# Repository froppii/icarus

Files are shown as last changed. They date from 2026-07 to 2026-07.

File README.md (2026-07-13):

# icarus
a retro vhs player themed mp3 player, complete with tactile switches and a fun volume button

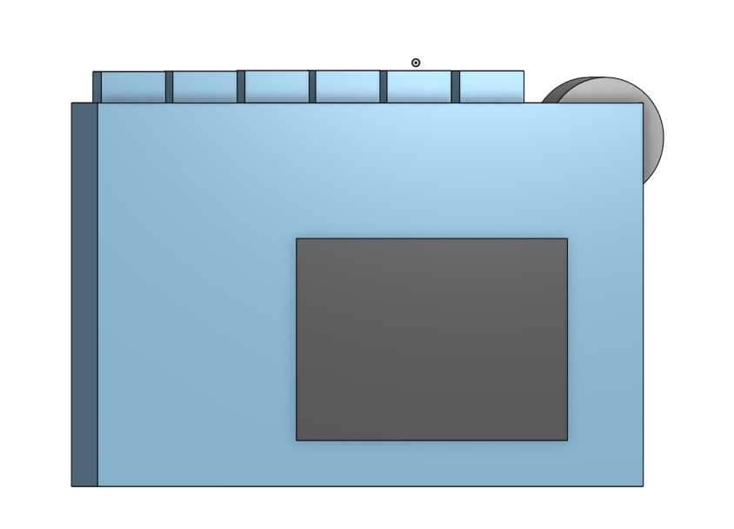
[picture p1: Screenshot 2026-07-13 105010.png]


## why?
ive always wanted a dedicated mp3 player so i can listen to music separately without draining my phone battery too quickly, aswell as not having to use spotify. im also learning more on how to make pcbs and 3d model case from this!

## parts and features
**parts**:
- mcu: esp32 s3 wroom 1
- dac: TAD5212IRGER
- display: ili9431
- power: 3.7V 2000mAh lipo battery
- pcb: 4 layers

**features**:
- 3.5mm headphone jack
- 2.8 inch display
- full sized sd card + 1-bit sdmmc audio streaming
- 5 tactile switches and a rotary encoder
- bluetooth 5.0
- programmable eq

## PCB
4 layer pcb

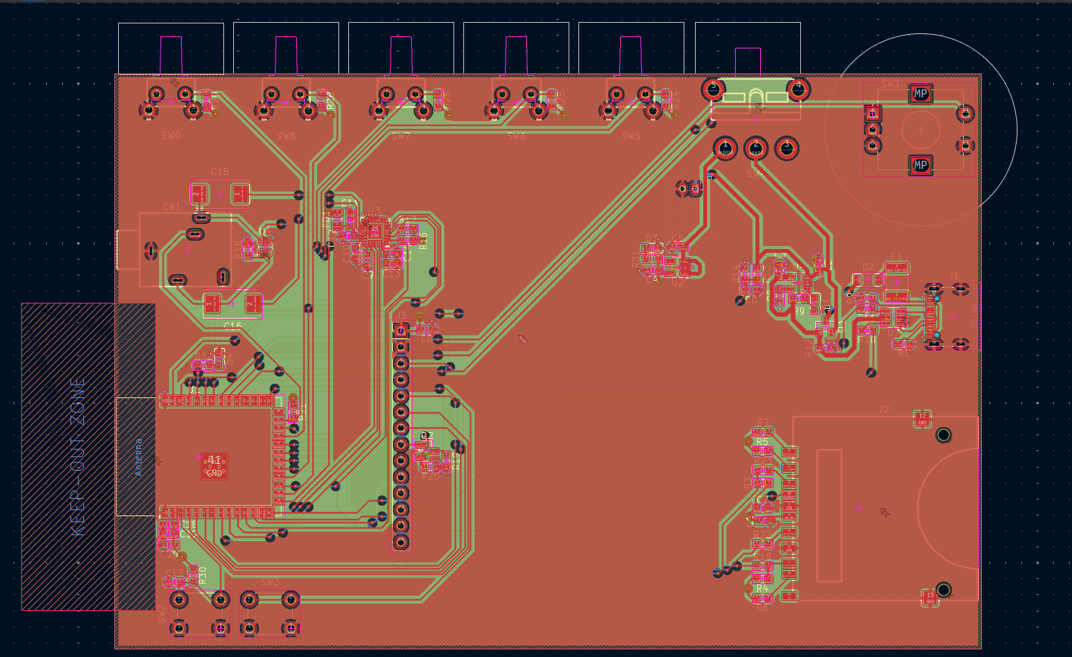
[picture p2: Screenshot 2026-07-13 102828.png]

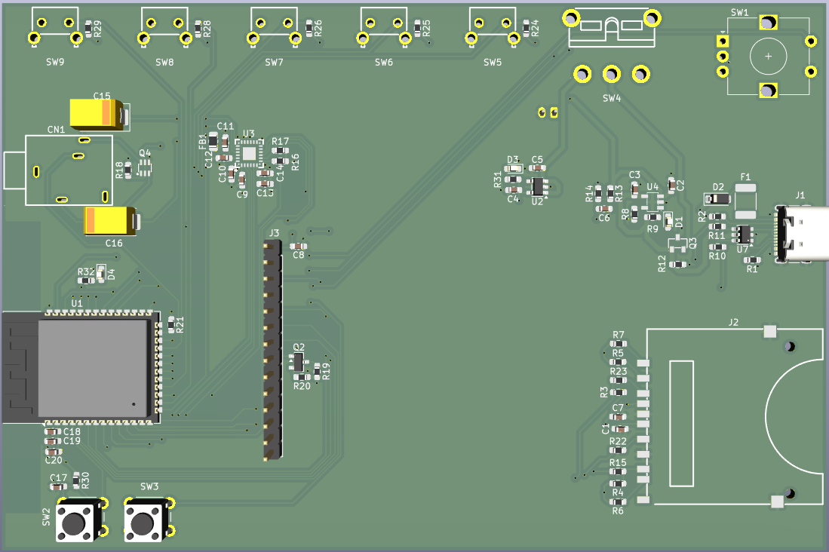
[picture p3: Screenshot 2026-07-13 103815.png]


## case
the case is still WIP! but i made a cad to show the general gist of how it would look like



## firmware
firmware coming soon

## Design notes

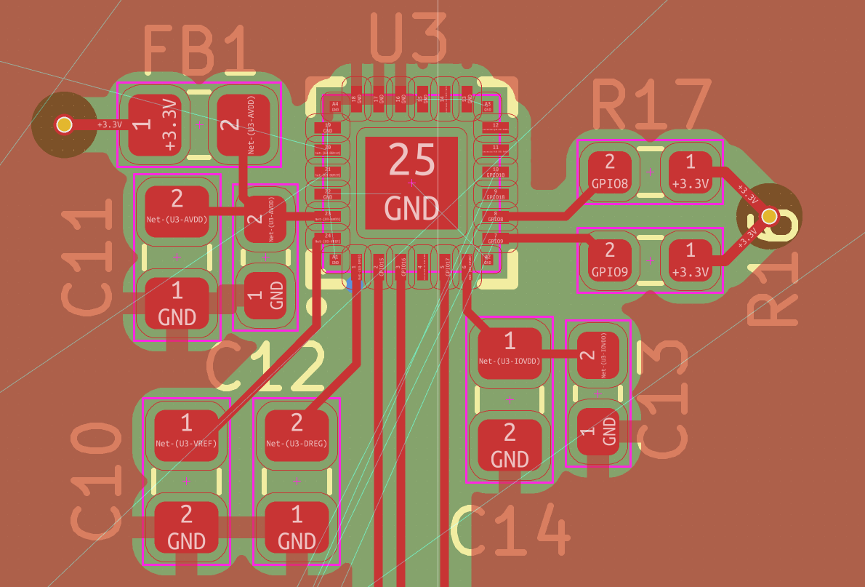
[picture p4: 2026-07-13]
Screenshot 2026-07-12 231309.png

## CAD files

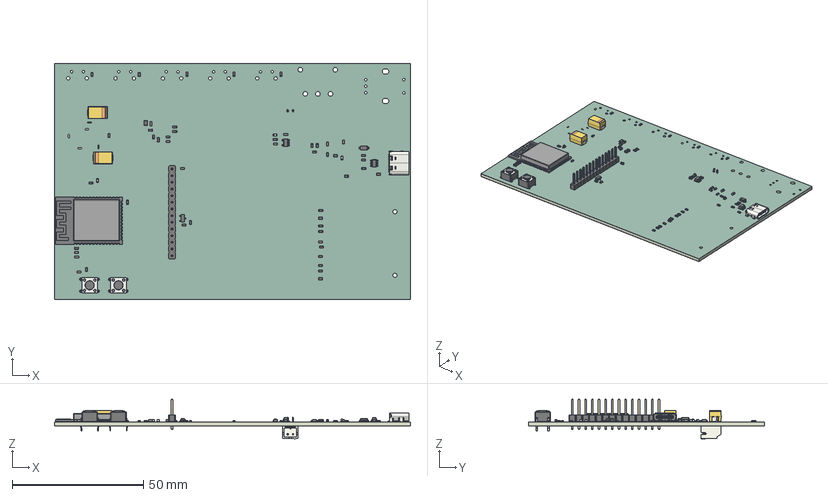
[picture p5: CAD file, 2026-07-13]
icarus.step
135.5 x 90.0 x 15.1 mm
R_0603_1608Metric x 31
C_0603_1608Metric x 18
R_0805_2012Metric
CP_EIA_7343_43_Kemet_X x 2
PinHeader_1x14_P254mm_Vertical
LED_0603_1608Metric x 3
SW_PUSH_6mm x 2
USB_C_Receptacle_16P_TopMnt_Horizontal_GCT_USB4105-xx-A
SOT-23
SOT-23-5
D_SOD-123
SOT-23-6
ESP32-S3-WROOM-1
JST_S2B_PH_K
icarus_soldermask x 2
icarus_PCB

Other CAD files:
.step

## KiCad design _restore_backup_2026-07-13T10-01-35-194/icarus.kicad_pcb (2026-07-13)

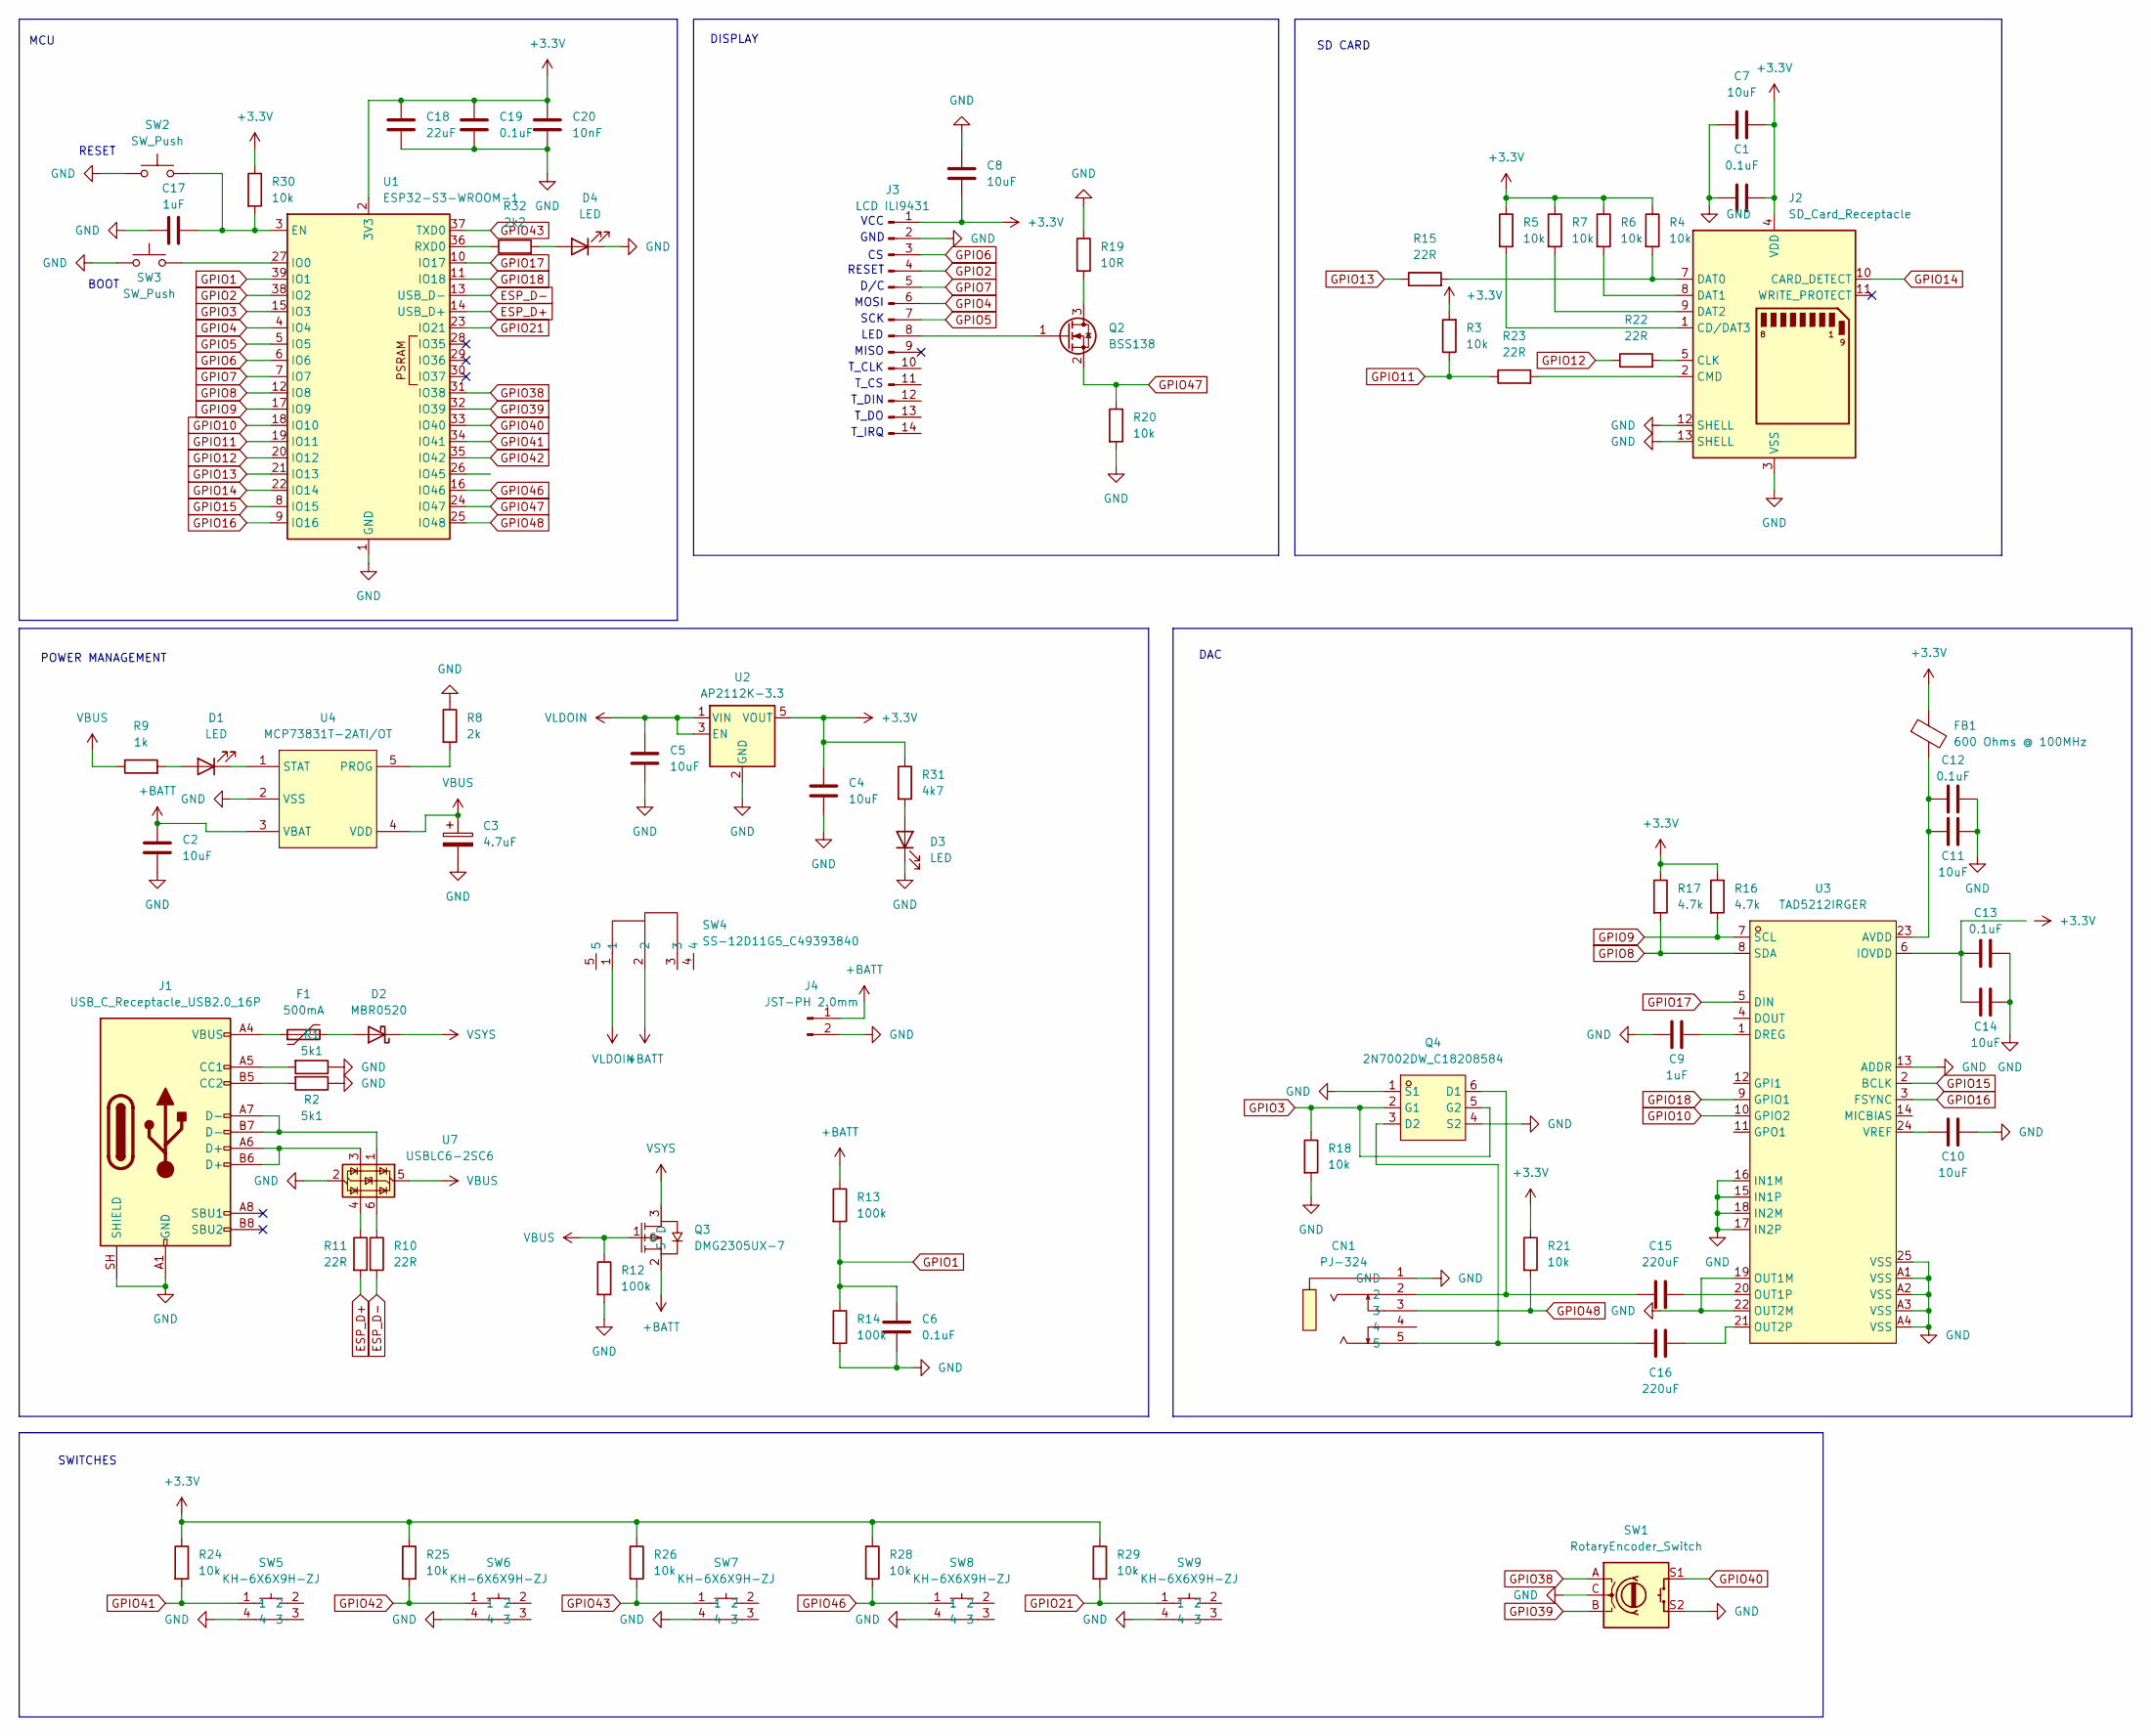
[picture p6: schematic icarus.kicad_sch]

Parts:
C1, C6, C12, C13, C19: 0.1uF; C_0603_1608Metric_Pad1.08x0.95mm_HandSolder
C2, C4, C5, C7, C8, C10, C11, C14: 10uF; C_0603_1608Metric_Pad1.08x0.95mm_HandSolder
C3: 4.7uF; C_0603_1608Metric_Pad1.08x0.95mm_HandSolder
C9, C17: 1uF; C_0603_1608Metric_Pad1.08x0.95mm_HandSolder
C15, C16: 220uF; CP_EIA-7343-43_Kemet-X_HandSolder
C18: 22uF; C_0603_1608Metric_Pad1.08x0.95mm_HandSolder
C20: 10nF; C_0603_1608Metric_Pad1.08x0.95mm_HandSolder
CN1: PJ-324; AUDIO-TH_PJ-324-M; MPN PJ-324; LCSC Part C22355738
D1, D3, D4: LED; LED_0603_1608Metric_Pad1.05x0.95mm_HandSolder
D2: MBR0520; D_SOD-123
F1: 500mA; Fuse_1812_4532Metric_Pad1.30x3.40mm_HandSolder
FB1: 600 Ohms @ 100MHz; R_0805_2012Metric_Pad1.20x1.40mm_HandSolder
J1: USB_C_Receptacle_USB2.0_16P; USB_C_Receptacle_GCT_USB4105-xx-A_16P_TopMnt_Horizontal
J2: SD_Card_Receptacle; SD-SMD_SD-006S-T
J3: LCD ILI9431; PinHeader_1x14_P2.54mm_Vertical
J4: JST-PH 2.0mm; JST_PH_S2B-PH-K_1x02_P2.00mm_Horizontal
Q2: BSS138; SOT-23
Q3: DMG2305UX-7; SOT-23-3_L2.9-W1.3-P1.90-LS2.4-BR; MPN DMG2305UX-7; LCSC Part C150470
Q4: 2N7002DW_C18208584; SOT-363_L2.1-W1.3-P0.65-LS2.3-BL; MPN 2N7002DW; LCSC Part C18208584
R1, R2: 5k1; R_0603_1608Metric_Pad0.98x0.95mm_HandSolder
R3, R4, R5, R6, R7, R18, R20, R21, R24, R25, R26, R28, R29, R30: 10k; R_0603_1608Metric_Pad0.98x0.95mm_HandSolder
R8: 2k; R_0603_1608Metric_Pad0.98x0.95mm_HandSolder
R9: 1k; R_0603_1608Metric_Pad0.98x0.95mm_HandSolder
R10, R11, R15, R22, R23: 22R; R_0603_1608Metric_Pad0.98x0.95mm_HandSolder
R12, R13, R14: 100k; R_0603_1608Metric_Pad0.98x0.95mm_HandSolder
R16, R17: 4.7k; R_0603_1608Metric_Pad0.98x0.95mm_HandSolder
R19: 10R; R_0603_1608Metric_Pad0.98x0.95mm_HandSolder
R31: 4k7; R_0603_1608Metric_Pad0.98x0.95mm_HandSolder
R32: 2k2; R_0603_1608Metric_Pad0.98x0.95mm_HandSolder
SW1: RotaryEncoder_Switch; RotaryEncoder_Alps_EC12E-Switch_Vertical_H20mm
SW2, SW3: SW_Push; SW_PUSH_6mm
SW4: SS-12D11G5_C49393840; SW-TH_SS-12D11G5; MPN SS-12D11G5; LCSC Part C49393840
SW5, SW6, SW7, SW8, SW9: KH-6X6X9H-ZJ; SW-TH_KH-6X6X9H-ZJ; MPN KH-6X6X9H-ZJ; LCSC Part C2837545
U1: ESP32-S3-WROOM-1
U2: AP2112K-3.3; SOT-23-5
U3: TAD5212IRGER; VQFN-24_L4.0-W4.0-P0.50-BL-EP2.1_1; MPN TAD5212IRGER; LCSC Part C45068920
U4: MCP73831T-2ATI/OT; SOT-23-5_L3.0-W1.7-P0.95-LS2.8-BR; MPN MCP73831T-2ATI/OT; LCSC Part C14879
U7: USBLC6-2SC6; SOT-23-6

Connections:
+3.3V: C1.2, C4.1, C7.1, C8.2, C18.1, C19.1, C20.1, FB1.1, J2.4 (VDD), J3.1, R3.2, R4.1, R5.1, R6.1, R7.1, R16.1, R17.1, R21.1, R24.1, R25.1, R26.1, R28.1, R29.1, R30.1, R31.1, U1.2 (3V3), U2.5 (VOUT)
+BATT: C2.1, J4.1, Q3.2 (S), R13.1, SW4.2, U4.3 (VBAT)
ESP_D+: R11.2, U1.14 (USB_D+)
ESP_D-: R10.2, U1.13 (USB_D-)
GND: C1.1, C2.2, C3.2, C4.2, C5.2, C6.2, C7.2, C8.1, C9.1, C10.2, C11.1, C12.1, C13.1, C14.2, C17.1, C18.2, C19.2, C20.2, CN1.1 (GND), D3.1 (K), D4.1 (K), J1.A1 (GND), J1.A12 (GND), J1.B1 (GND), J1.B12 (GND), J1.SH (SHIELD), J2.3 (VSS), J2.6 (VSS), J2.12 (SHELL), J2.13 (SHELL), J3.2, J4.2, Q4.1 (S1), Q4.4 (S2), R1.1, R2.1, R8.1, R12.2, R14.2, R18.2, R19.1, R20.2, SW1.C, SW1.S2, SW2.1, SW3.1, SW5.4, SW6.4, SW7.4, SW8.4, SW9.4, U1.1 (GND), U1.40 (GND), U1.41 (GND), U2.2 (GND), U3.13 (ADDR), U3.15 (IN1P), U3.16 (IN1M), U3.17 (IN2P), U3.18 (IN2M), U3.19 (OUT1M), U3.22 (OUT2M), U3.25 (VSS), U3.A1 (VSS), U3.A2 (VSS), U3.A3 (VSS), U3.A4 (VSS), U4.2 (VSS), U7.2 (GND)
GPIO1: C6.1, R13.2, R14.1, U1.39 (IO1)
GPIO2: J3.4, U1.38 (IO2)
GPIO3: Q4.2 (G1), Q4.5 (G2), R18.1, U1.15 (IO3)
GPIO4: J3.6, U1.4 (IO4)
GPIO5: J3.7, U1.5 (IO5)
GPIO6: J3.3, U1.6 (IO6)
GPIO7: J3.5, U1.7 (IO7)
GPIO8: R17.2, U1.12 (IO8), U3.8 (SDA)
GPIO9: R16.2, U1.17 (IO9), U3.7 (SCL)
GPIO10: U1.18 (IO10), U3.10 (GPIO2)
GPIO11: R3.1, R23.1, U1.19 (IO11)
GPIO12: R22.1, U1.20 (IO12)
GPIO13: R15.1, U1.21 (IO13)
GPIO14: J2.10 (CARD_DETECT), U1.22 (IO14)
GPIO15: U1.8 (IO15), U3.2 (BCLK)
GPIO16: U1.9 (IO16), U3.3 (FSYNC)
GPIO17: U1.10 (IO17), U3.5 (DIN)
GPIO18: U1.11 (IO18), U3.9 (GPIO1)
GPIO21: R29.2, SW9.1, U1.23 (IO21)
GPIO38: SW1.A, U1.31 (IO38)
GPIO39: SW1.B, U1.32 (IO39)
GPIO40: SW1.S1, U1.33 (IO40)
GPIO41: R24.2, SW5.1, U1.34 (IO41)
GPIO42: R25.2, SW6.1, U1.35 (IO42)
GPIO43: R26.2, SW7.1, U1.37 (TXD0)
GPIO46: R28.2, SW8.1, U1.16 (IO46)
GPIO47: Q2.2 (S), R20.1, U1.24 (IO47)
GPIO48: CN1.3, R21.2, U1.25 (IO48)
unnamed: D1.2 (A), R9.2
unnamed: D1.1 (K), U4.1 (STAT)
unnamed: D2.2 (A), F1.2
unnamed: D3.2 (A), R31.2
unnamed: D4.2 (A), R32.2
unnamed: F1.1, J1.A4 (VBUS), J1.A9 (VBUS), J1.B4 (VBUS), J1.B9 (VBUS)
unnamed: J1.A5 (CC1), R1.2
unnamed: J1.B5 (CC2), R2.2
unnamed: J1.A6 (D+), J1.B6 (D+), U7.3 (I/O2)
unnamed: J1.A7 (D-), J1.B7 (D-), U7.1 (I/O1)
unnamed: J2.1 (CD/DAT3), R5.2
unnamed: J2.5 (CLK), R22.2
unnamed: J2.2 (CMD), R23.2
unnamed: J2.7 (DAT0), R4.2, R15.2
unnamed: J2.8 (DAT1), R6.2
unnamed: J2.9 (DAT2), R7.2
unnamed: J3.8, Q2.1 (G)
unnamed: Q2.3 (D), R19.2
unnamed: C15.2, CN1.2, Q4.6 (D1)
unnamed: C16.1, CN1.5, Q4.3 (D2)
unnamed: R10.1, U7.6 (I/O1)
unnamed: R11.1, U7.4 (I/O2)
unnamed: C17.2, R30.2, SW2.2, U1.3 (EN)
unnamed: SW3.2, U1.27 (IO0)
unnamed: R32.1, U1.36 (RXD0)
unnamed: C11.2, C12.2, FB1.2, U3.23 (AVDD)
unnamed: C9.2, U3.1 (DREG)
unnamed: C13.2, C14.1, U3.6 (IOVDD)
unnamed: C15.1, U3.20 (OUT1P)
unnamed: C16.2, U3.21 (OUT2P)
unnamed: C10.1, U3.24 (VREF)
unnamed: R8.2, U4.5 (PROG)
VBUS: C3.1, Q3.1 (G), R9.1, R12.1, U4.4 (VDD), U7.5 (VBUS)
VLDOIN: C5.1, SW4.1, U2.1 (VIN), U2.3 (EN)
VSYS: D2.1 (K), Q3.3 (D)

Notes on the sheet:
SD CARD
T_DIN
RESET
T_IRQ
BOOT
SWITCHES
DAC
MOSI
T_CLK
SCK
LED
D/C
T_DO
MCU
MISO
POWER MANAGEMENT
T_CS
VCC
GND
RESET
DISPLAY

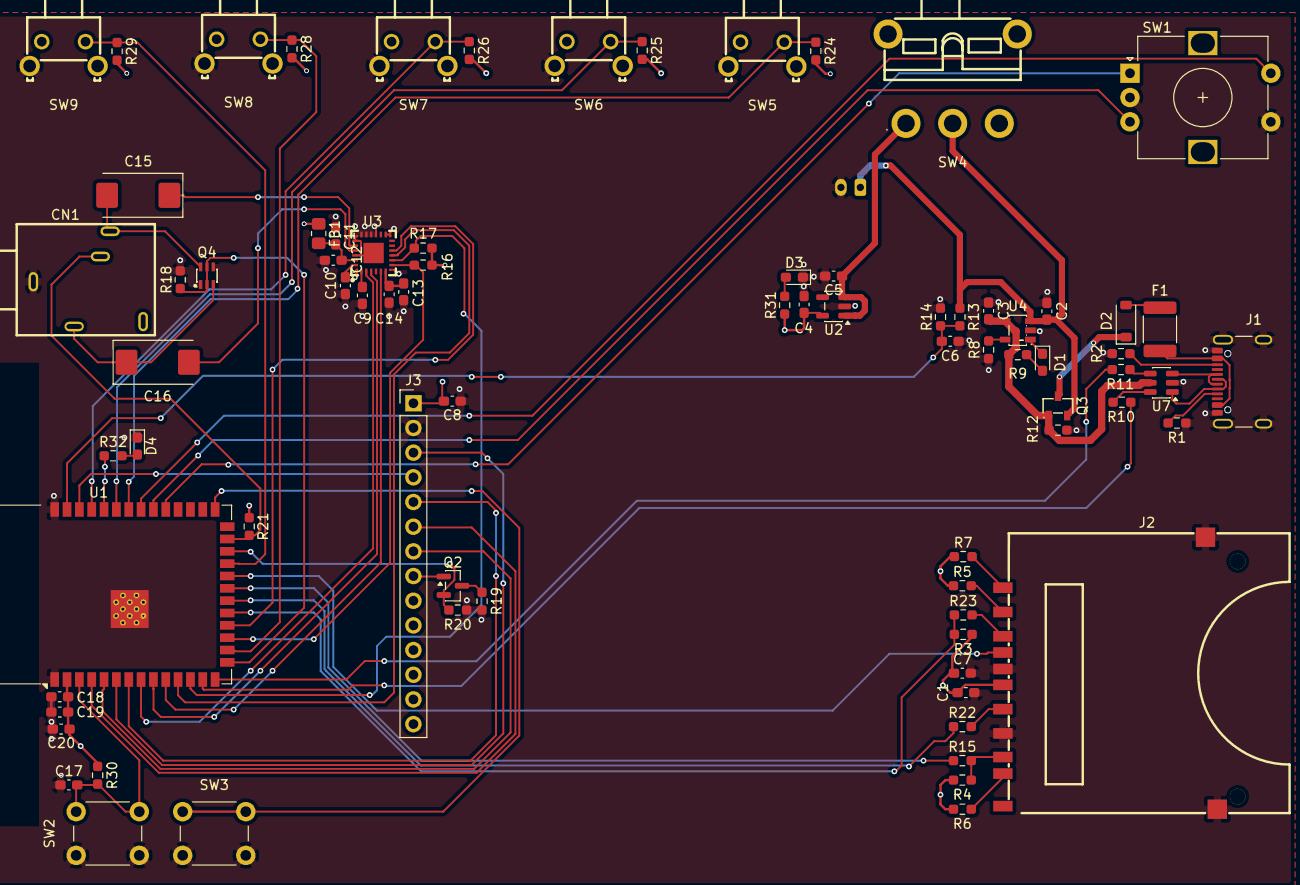
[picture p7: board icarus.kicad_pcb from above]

Board: 4 copper layers, 79 parts (1 on the bottom side), 68 nets.

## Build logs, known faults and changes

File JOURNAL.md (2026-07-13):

## 22/04/2026

I tried looking at components I needed and stuff!! I still don't know how to pick a speaker etc, but we'll figure it out. I made a sketch of what i want the case to look like ish and we decided on some components to use like the display and battery, also a bit of CAD to figure out the dimensions!

**Time spent : 1**

**Total time : 1**

## 24/04/2026
started making the pcb!!! still a bit confused on what to do but a few youtube vids and google searches later im starting to get the hang of it. after looking a bit i decided to use the esp32 s3 wroom 1 yay!!

**Time spent : 2**

**Total time : 3**

## 06/07/2026

progress after nearly 2 months, tried to continue figure out what modules and components to use. looked into how and what i need to charge lipo batteries, decided on the tp4056 chip components and found out i needed a voltage regulator. wanted to go with ht7333 but found out that the output current is too low(250-300mA, esp32 needs atleast 500mA) so switched to ap2112k (much stabler, 600mA)

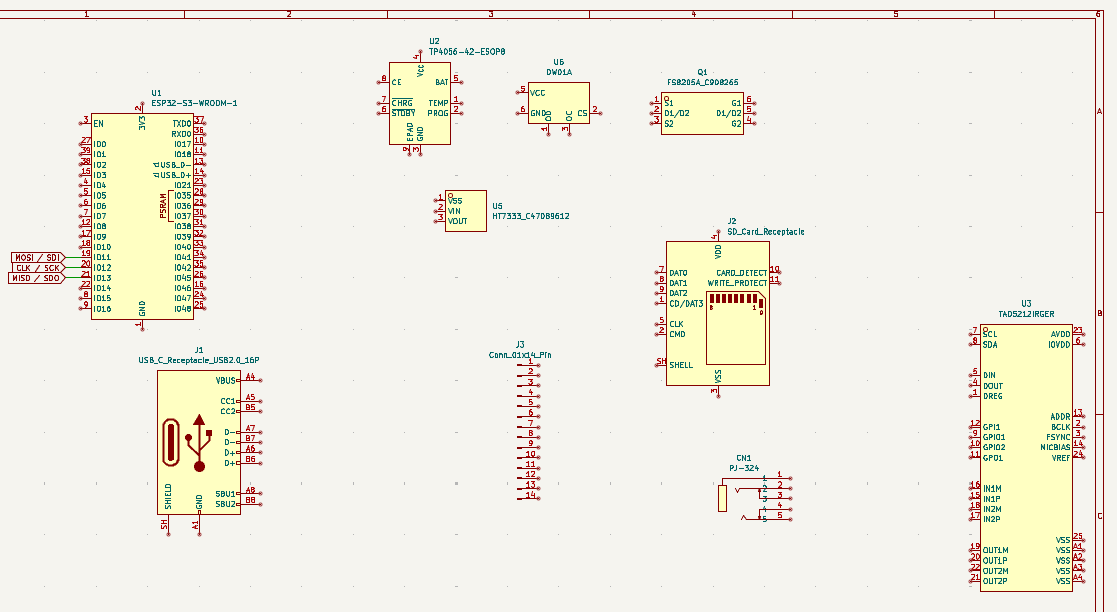
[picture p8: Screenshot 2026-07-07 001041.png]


**Time spent : 3**

**Total time : 6**

## 07/07/2026

more schematics work yay....! searching for an alternative to the DAC i initially wanted to use (TAS5721) because turns out its not a headphone amplifier, speaker only. decided to abandon the idea of having speakers for the mp3 player and doing headphone only. planning on adding a new bluetooth audio module but alas the search continues

**Time spent : 4**

**Total time : 10**

## 08/07/2026

holy lockin. i learned what pullups are... the ones with resistors and some electronics basics because i have the memory of a goldfish. looked into lipo charging circuits but found out you can use these magical things called power management ics, which basically has everything in one. theres so little resources on the axp2101 pmic im using so ill be giving up on it for now and get back to it eventually sob. good news is i figured out how to wire the sd card!!! yippie!!!1 and the usbc to some extent

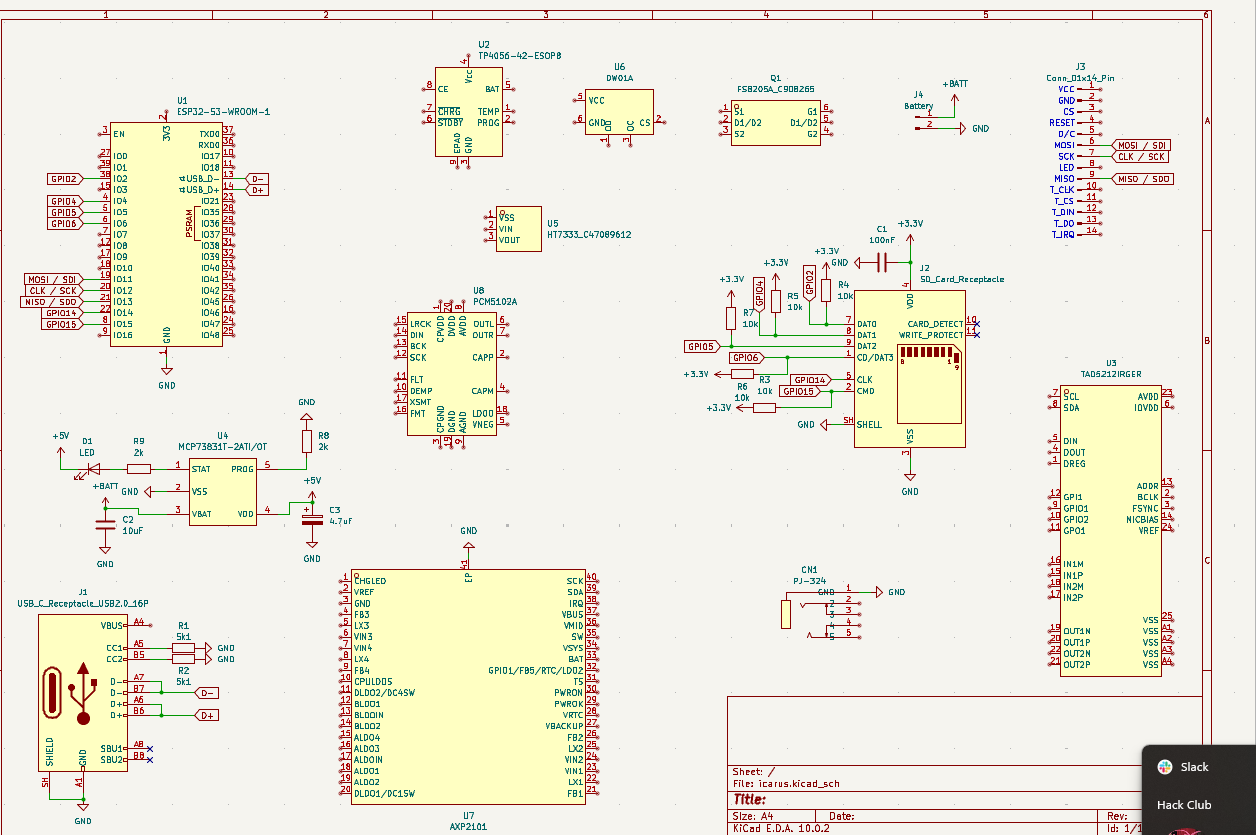
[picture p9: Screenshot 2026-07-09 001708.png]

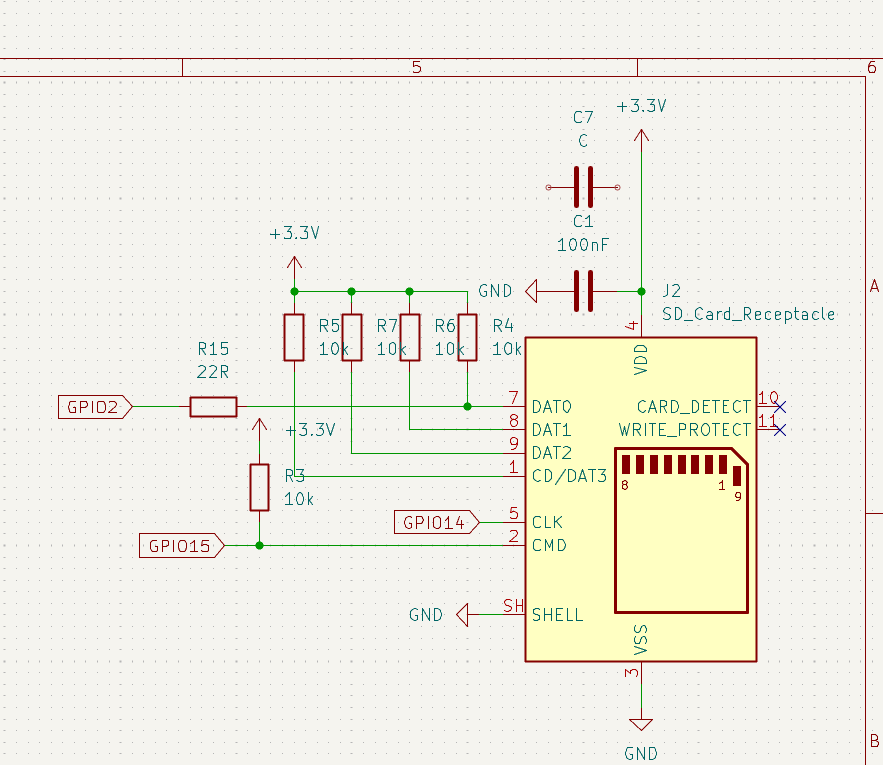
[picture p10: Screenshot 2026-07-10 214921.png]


**Time spent : 8**

**Total time : 18**

## 10/07/2026

today i spent more time doing schematics, was home the whole day so i locked in!! i figured out how to connect my DAC, aswell as the whole power system. abandoned the pmic because it was too complex for me sob,, oh also the display!

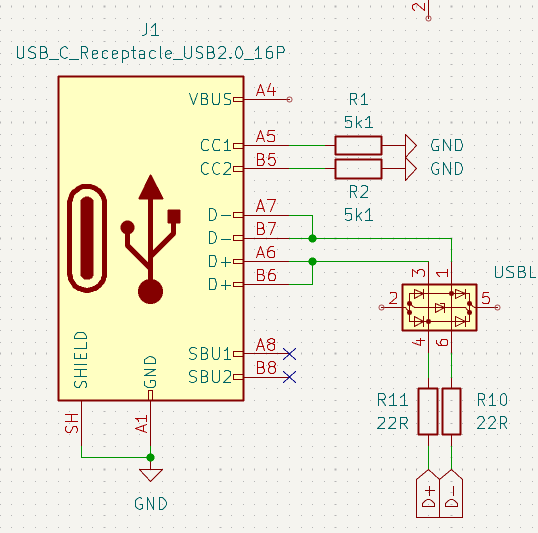
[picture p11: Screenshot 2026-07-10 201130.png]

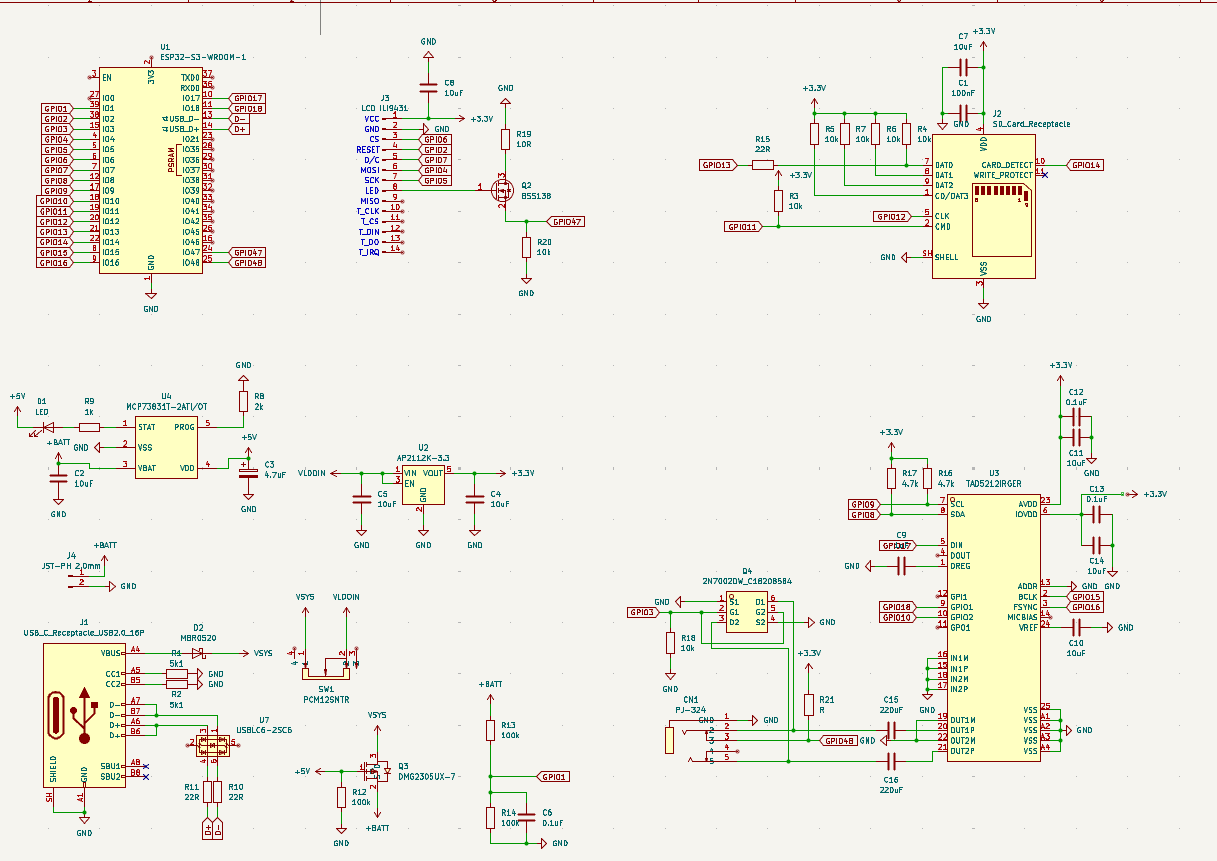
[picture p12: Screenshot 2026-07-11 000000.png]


**Time spent : 14.5**

**Total time : 32.5**

## 11/07/2026

more locking in, for 15 hrs!! wowie. finished my schematics, and started routing. twas my first time routing something with this much parts and i had to redo it once because it was spaghetti. it is also my first time doing ground fills TwT. routing is like 50% done hoping to finish tmr (my aunt woke up from me working so i had to stop TwT)

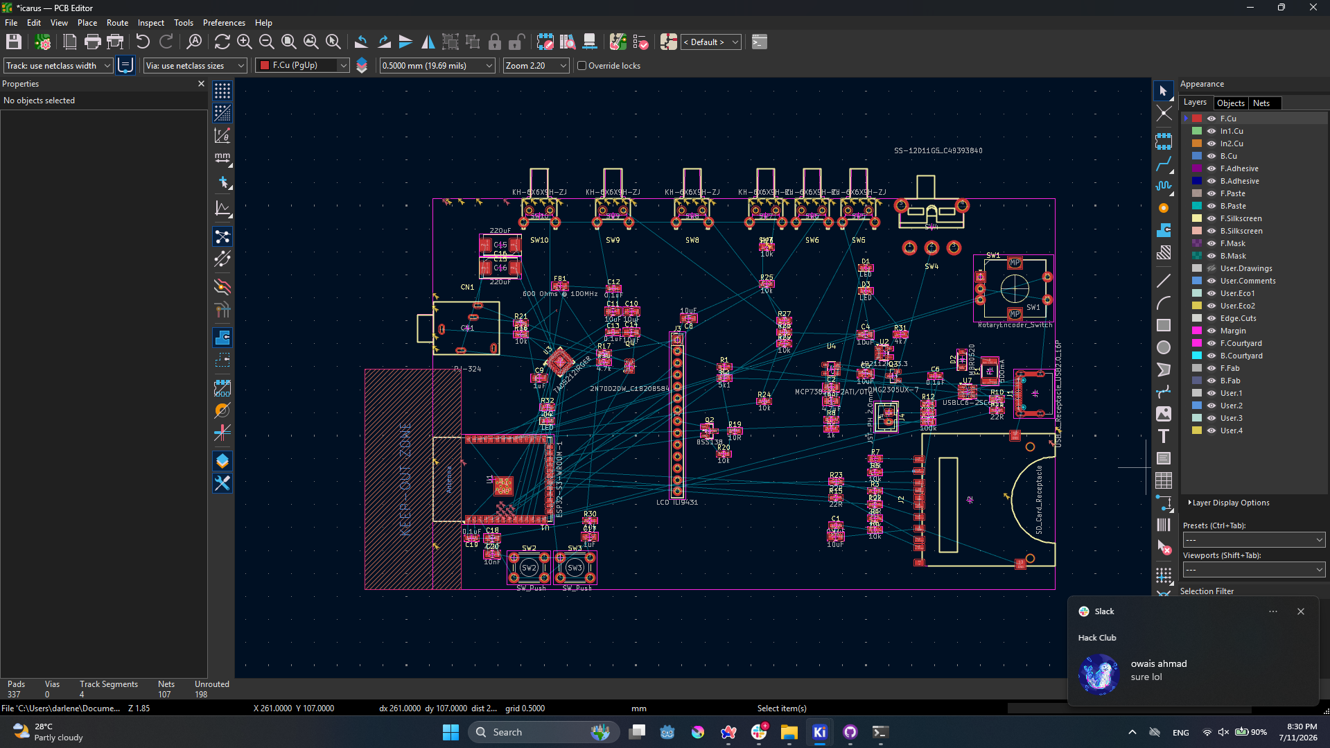
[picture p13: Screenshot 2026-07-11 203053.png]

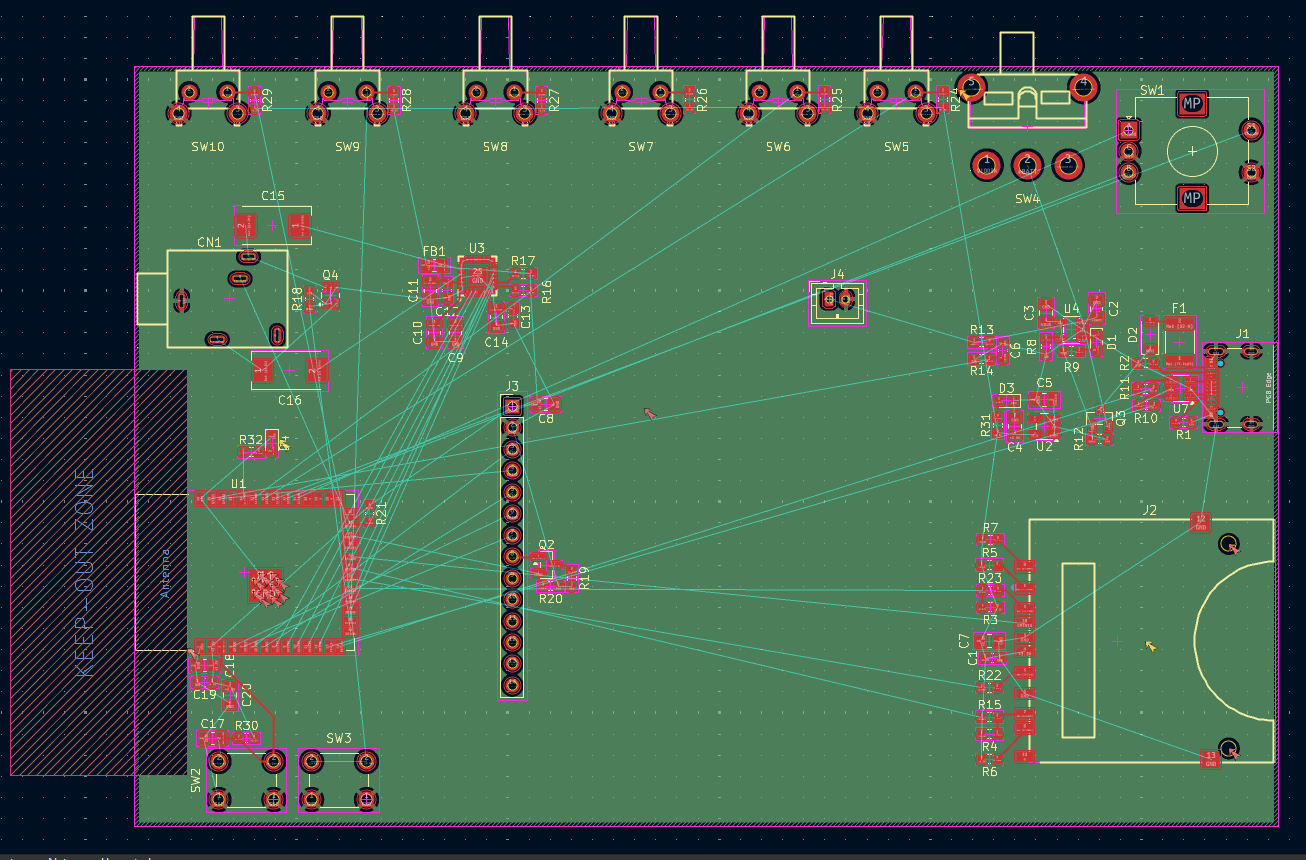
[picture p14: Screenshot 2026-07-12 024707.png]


**Time spent : 15**
**Total time : 47.5**

## 12/07/2026

even more routing, this thing isnt finishing istg. i also learnt how to use vias and all, mostly how to route properly this is starting to get a little fun. today is just routing again. (my aunt woke up from me working again so i also had to stop early)

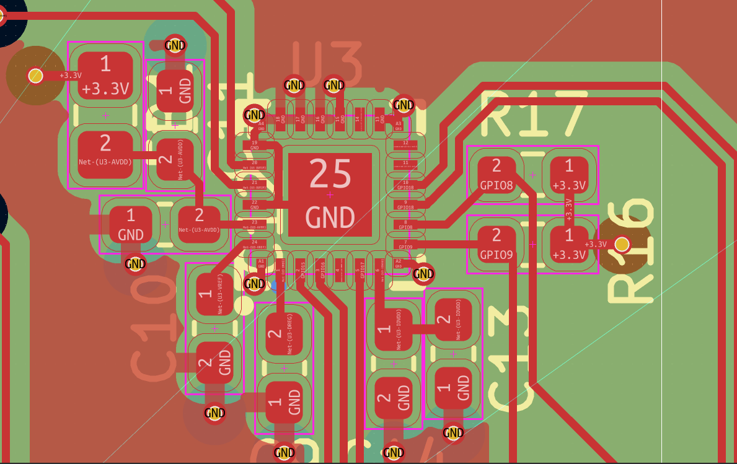
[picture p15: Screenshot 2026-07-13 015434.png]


**Time spent : 7**
**Total time : 54.5**

## 13/07/2026

I FINISHED ROUTING!! YAY!! now we on to cadding!! cadding!! cadding!!

 



**Time spent : 10**
**Total time : 64.5**
